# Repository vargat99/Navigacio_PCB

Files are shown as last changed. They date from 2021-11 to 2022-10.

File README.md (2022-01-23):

# KAPCSRAJZON
## Motor control: pipa
## Sensors
	GPS: pipa
	IMU: kéne egy level shifter és egy 1.8V táp
## Power management
	ShengYang datasheet ennyit tudott
## MCU Logic
	GPS, földek be van kötve
	kijövő táp logikai 3.3V, 5V be van kötve
	MCU bemenő táp be van kötve
	
## Kell még
	motor_mode
	motor ki/be kapcsolás
	enkóderek
	pwm vezérlés

	sensorok I2C, SPI ...

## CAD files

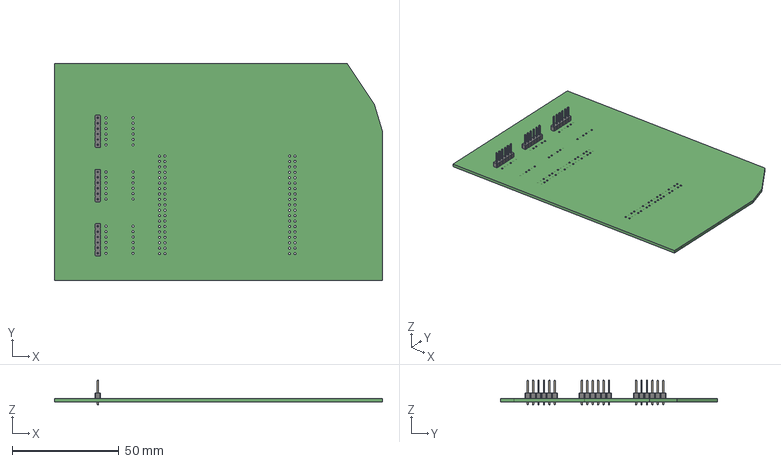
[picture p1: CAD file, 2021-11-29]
lego_robot.step
153.7 x 101.6 x 11.5 mm

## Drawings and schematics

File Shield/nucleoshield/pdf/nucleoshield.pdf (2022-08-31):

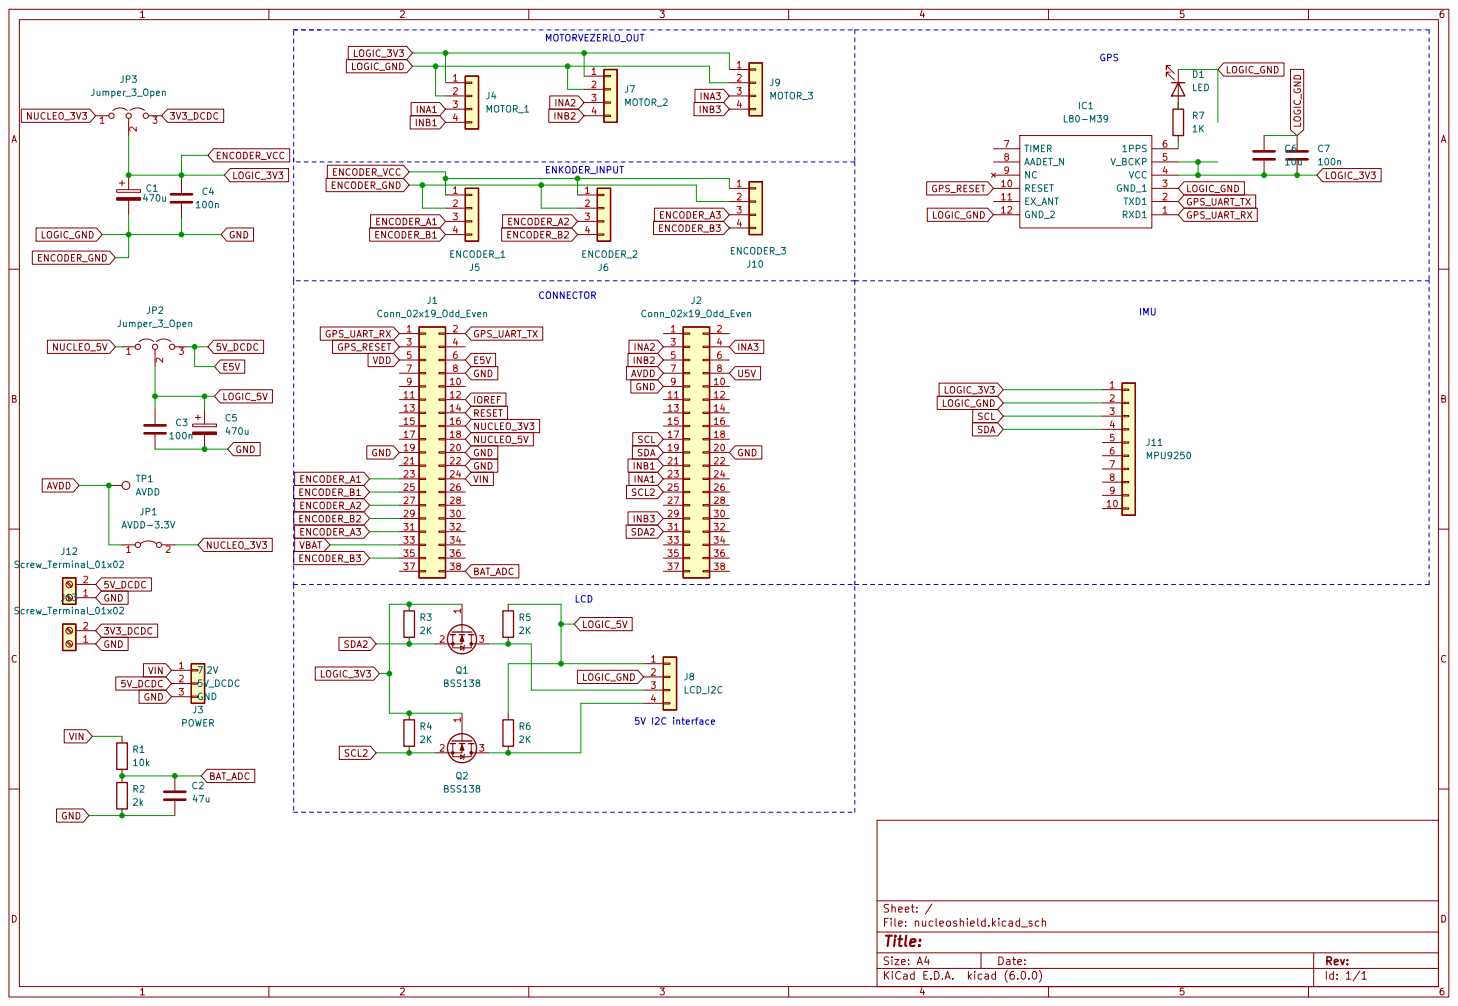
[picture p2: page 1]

ENCODER_VCC | J10 ENCODER_3

J1 Conn_02x19_Odd_Even

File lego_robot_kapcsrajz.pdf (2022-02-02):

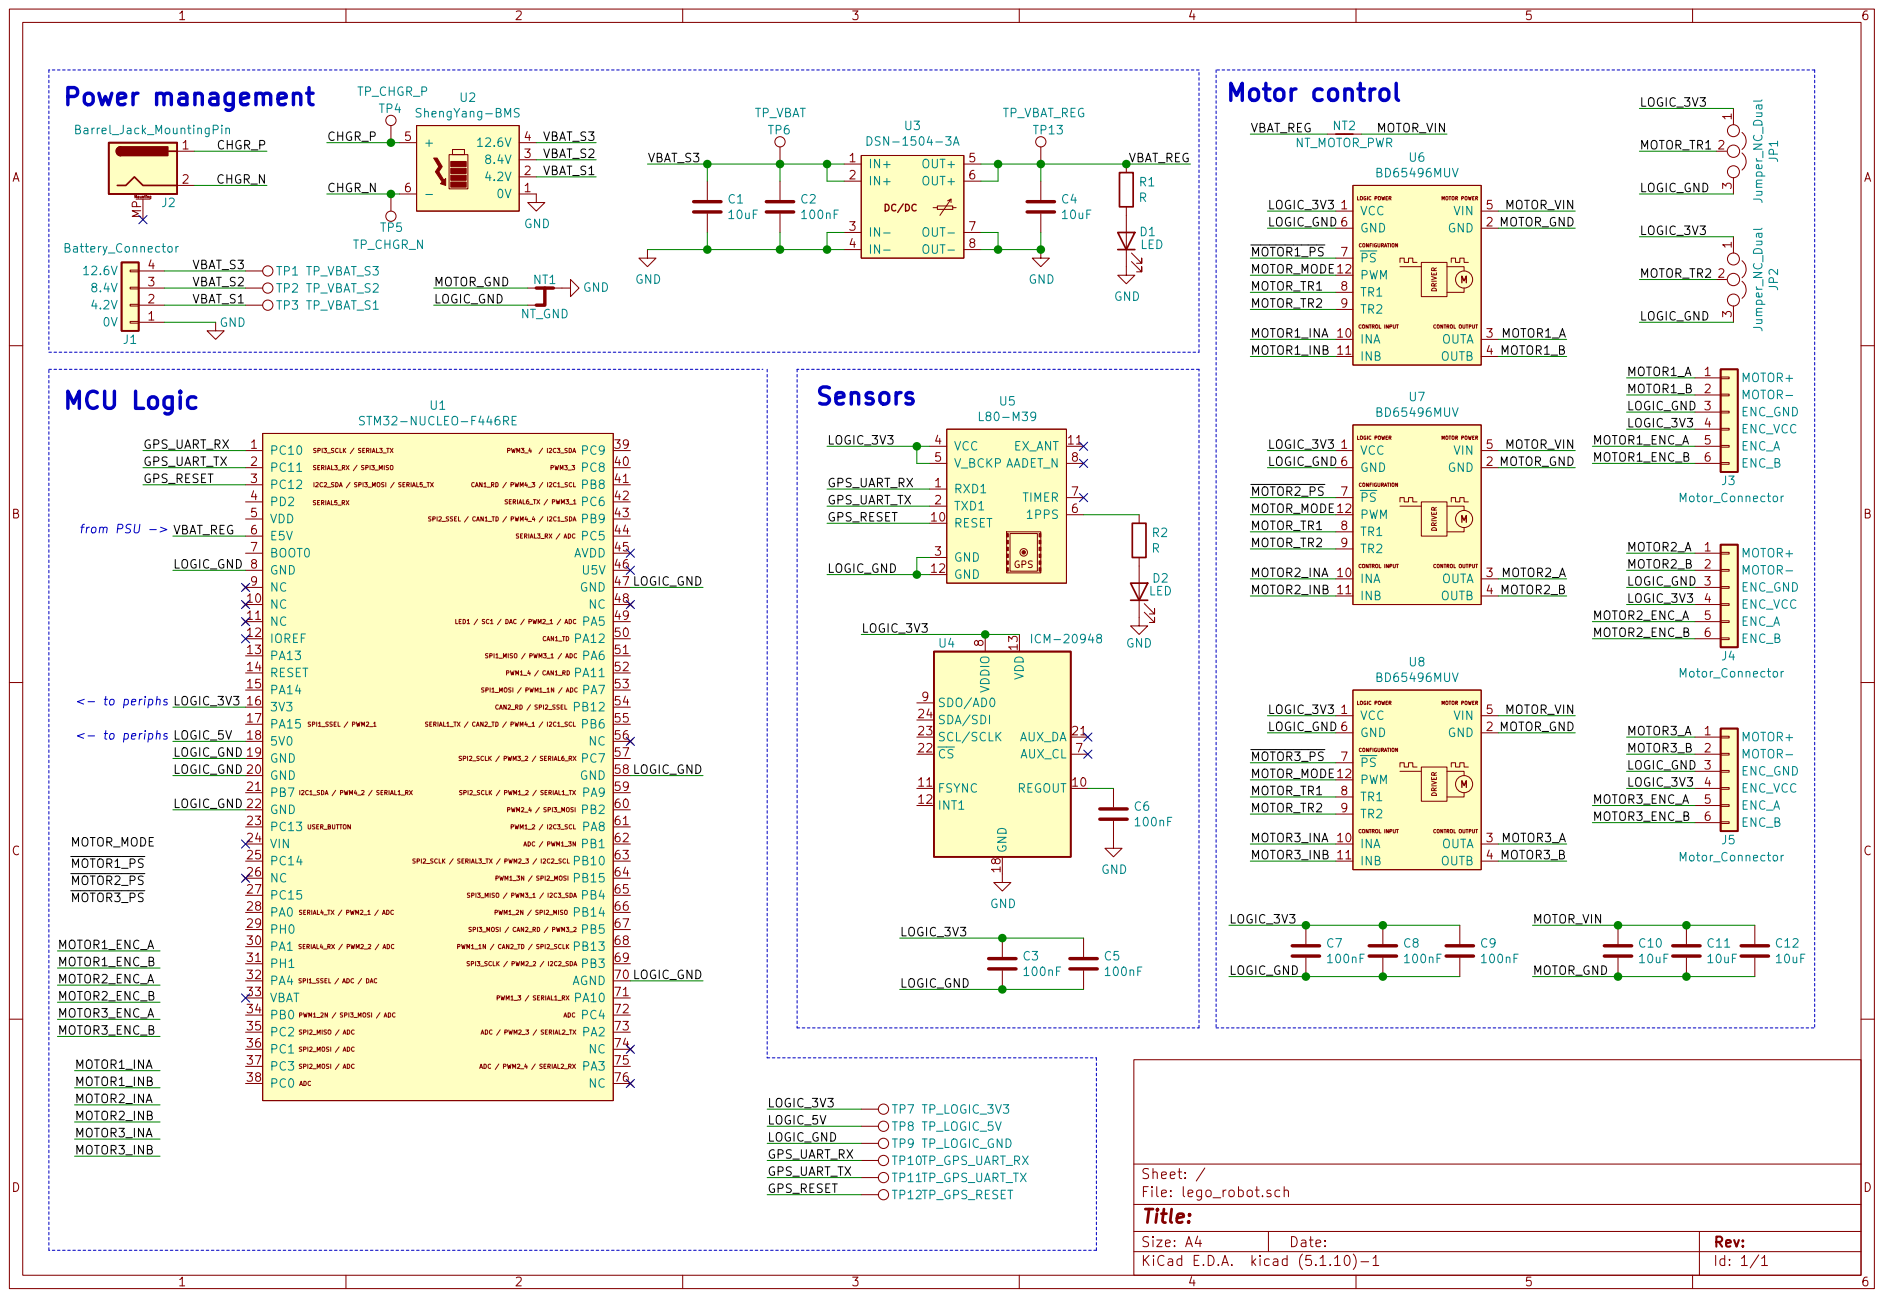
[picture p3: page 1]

from PSU -> MCU Logic

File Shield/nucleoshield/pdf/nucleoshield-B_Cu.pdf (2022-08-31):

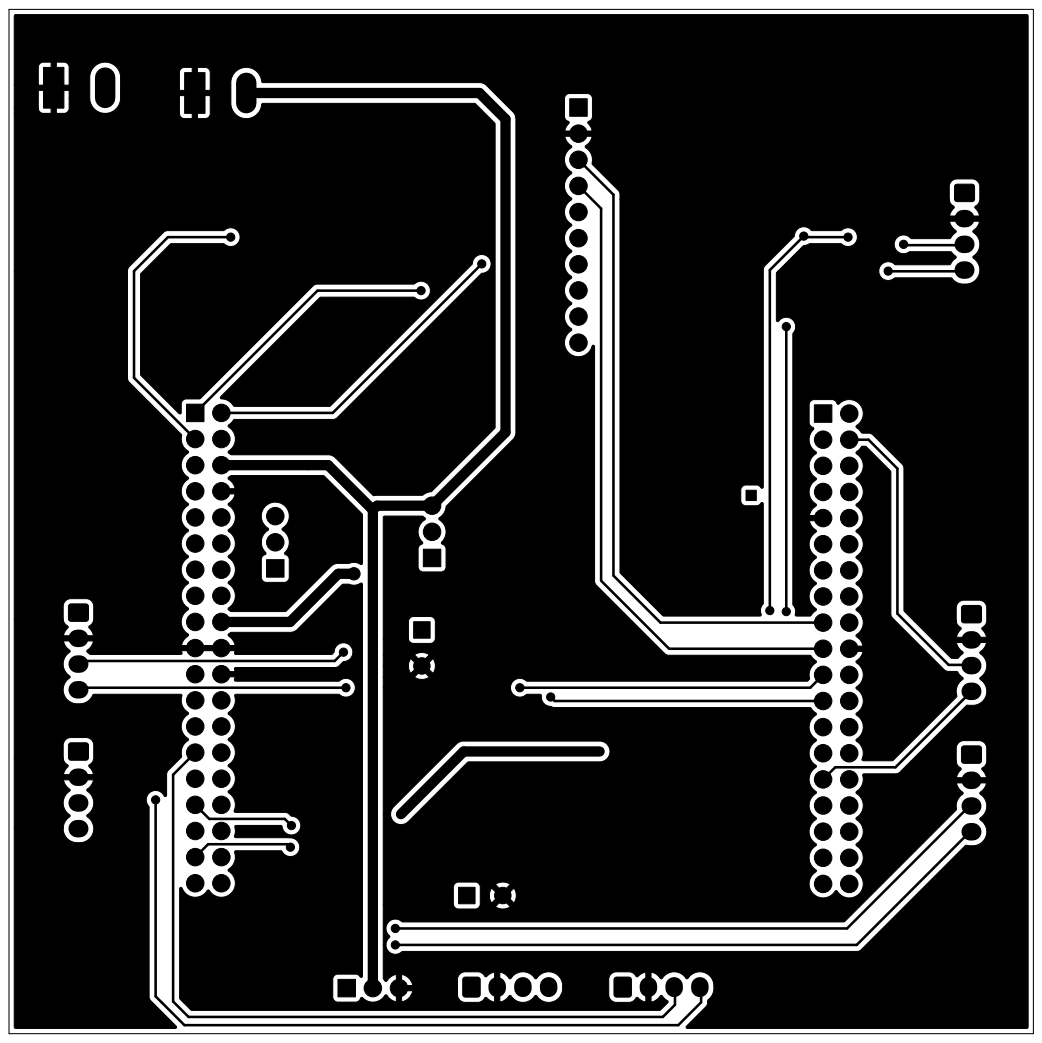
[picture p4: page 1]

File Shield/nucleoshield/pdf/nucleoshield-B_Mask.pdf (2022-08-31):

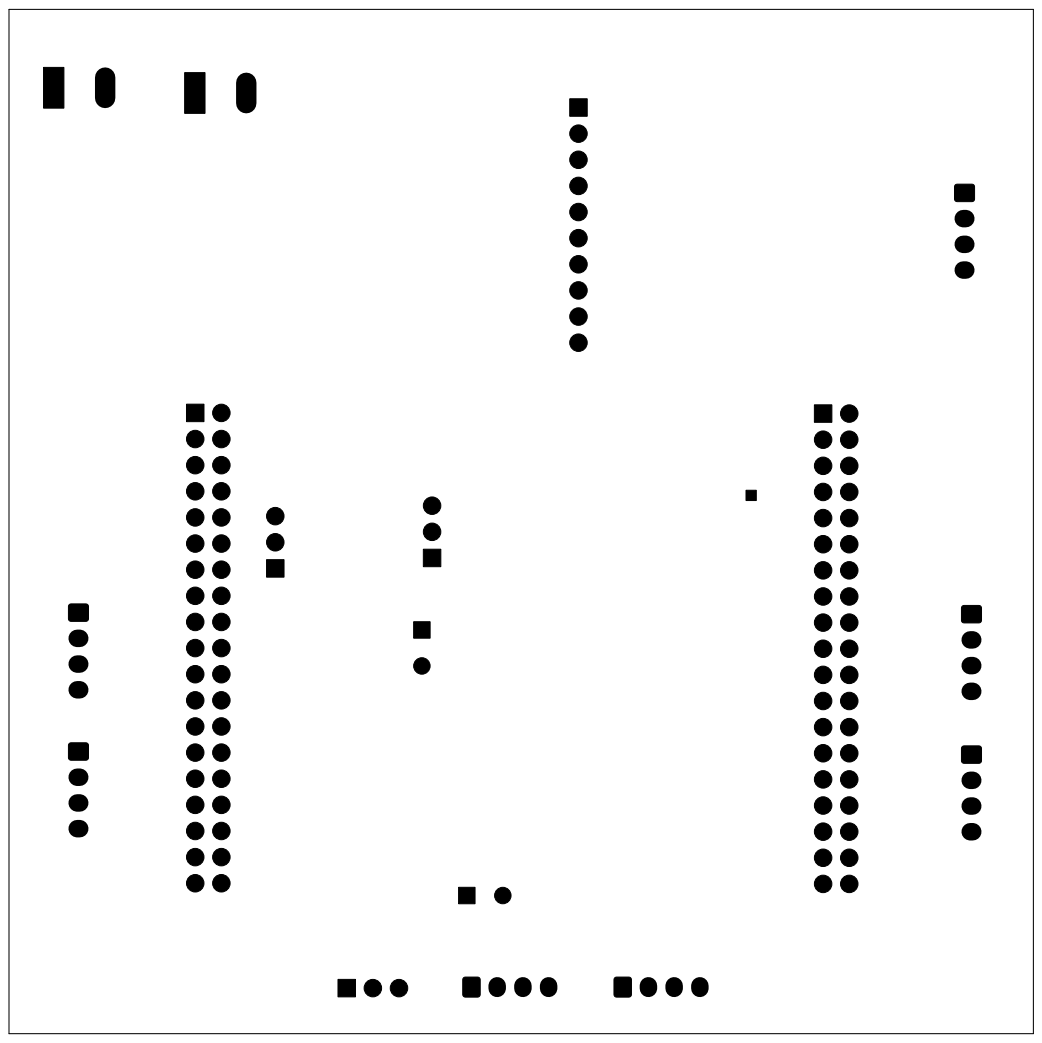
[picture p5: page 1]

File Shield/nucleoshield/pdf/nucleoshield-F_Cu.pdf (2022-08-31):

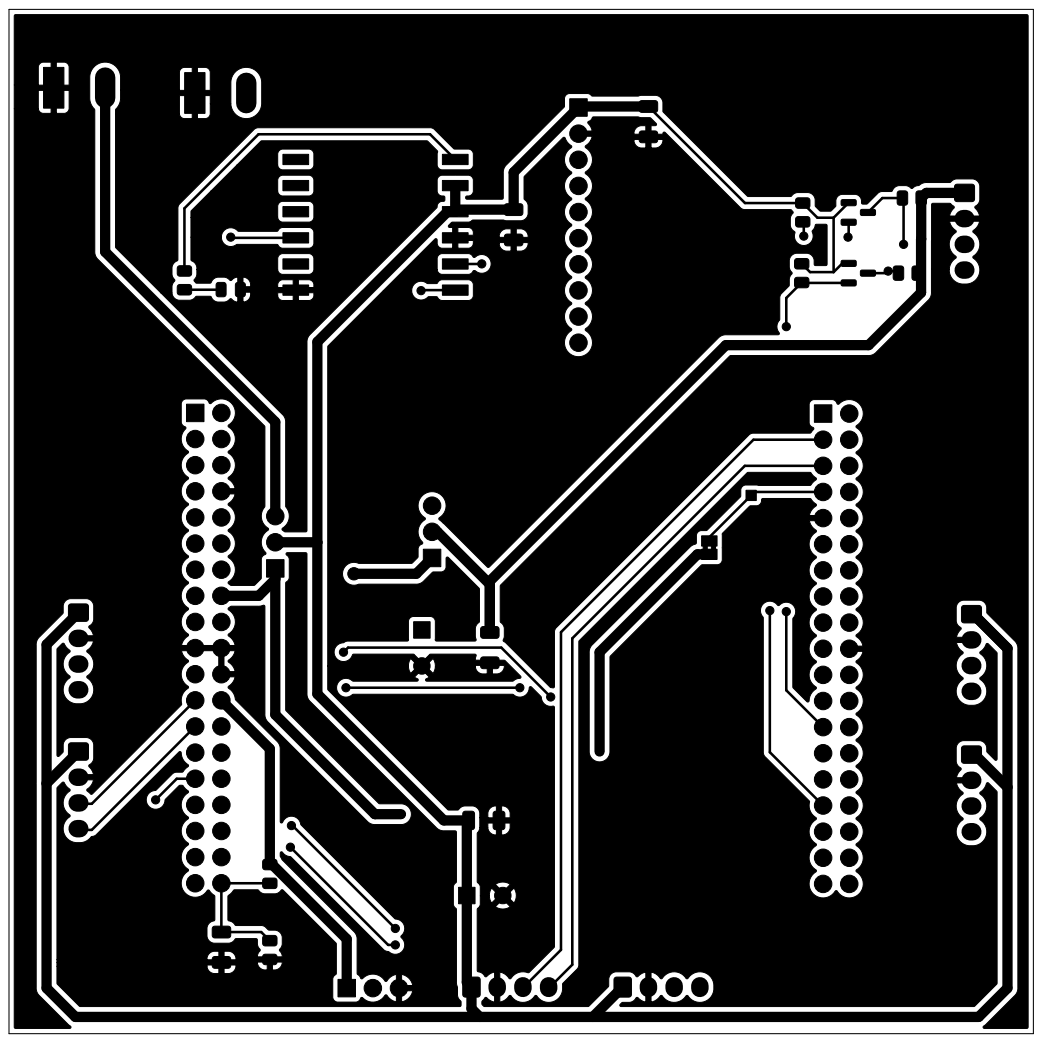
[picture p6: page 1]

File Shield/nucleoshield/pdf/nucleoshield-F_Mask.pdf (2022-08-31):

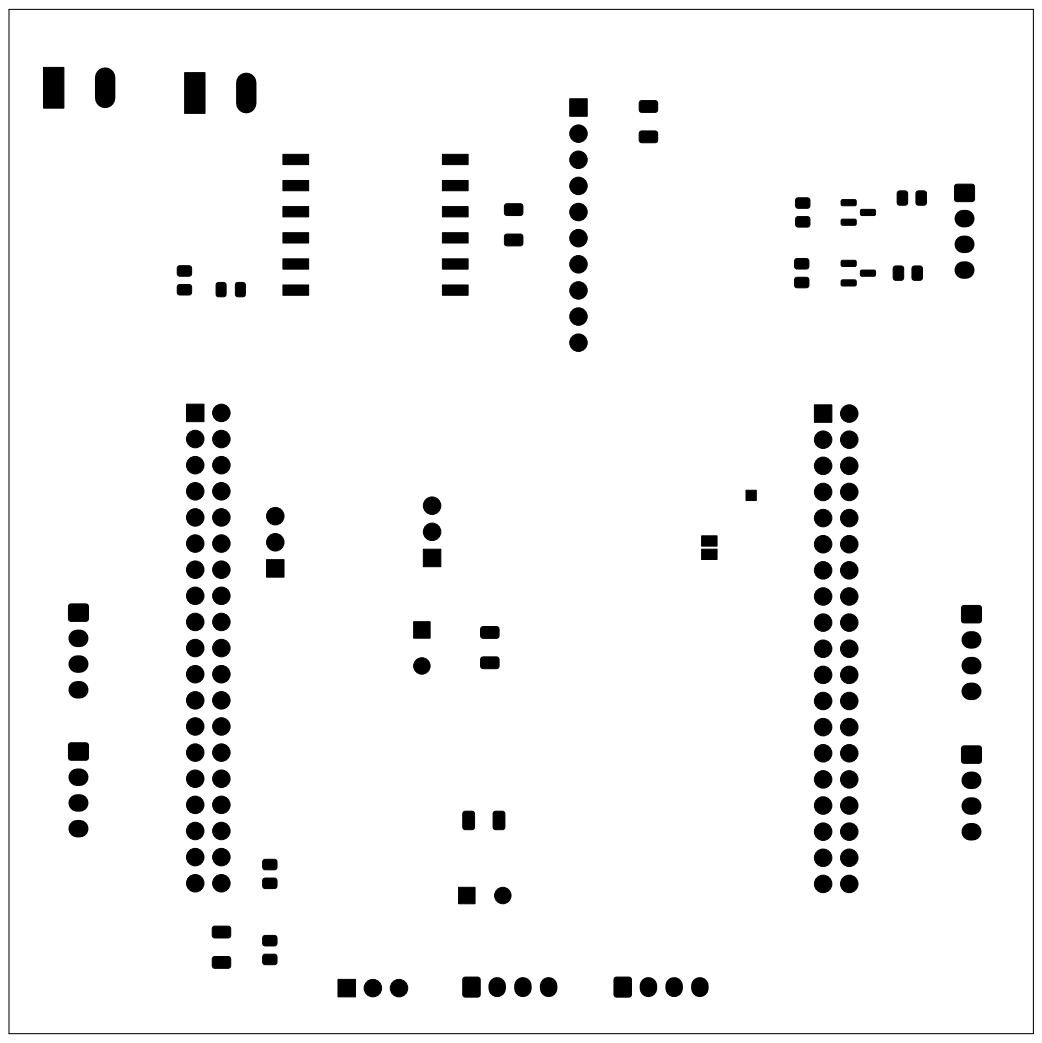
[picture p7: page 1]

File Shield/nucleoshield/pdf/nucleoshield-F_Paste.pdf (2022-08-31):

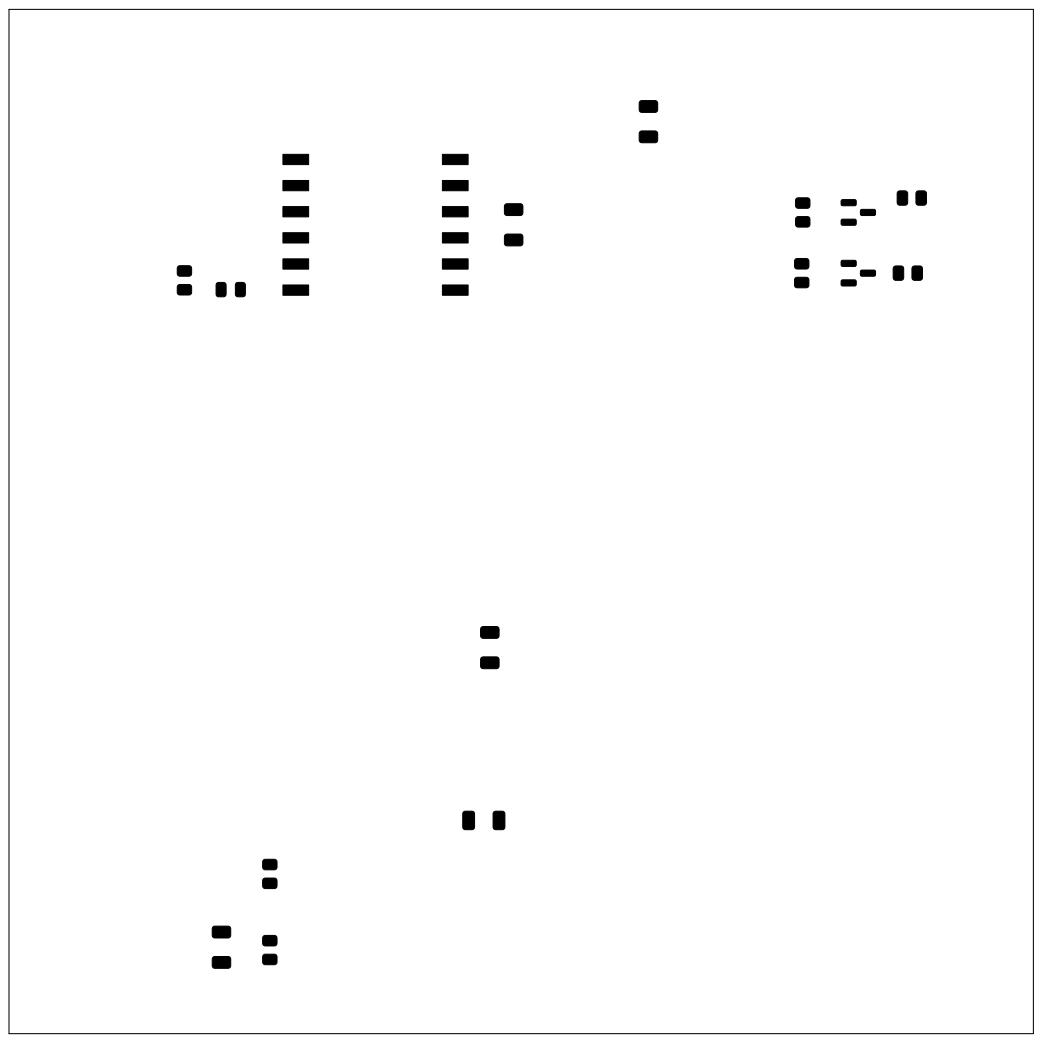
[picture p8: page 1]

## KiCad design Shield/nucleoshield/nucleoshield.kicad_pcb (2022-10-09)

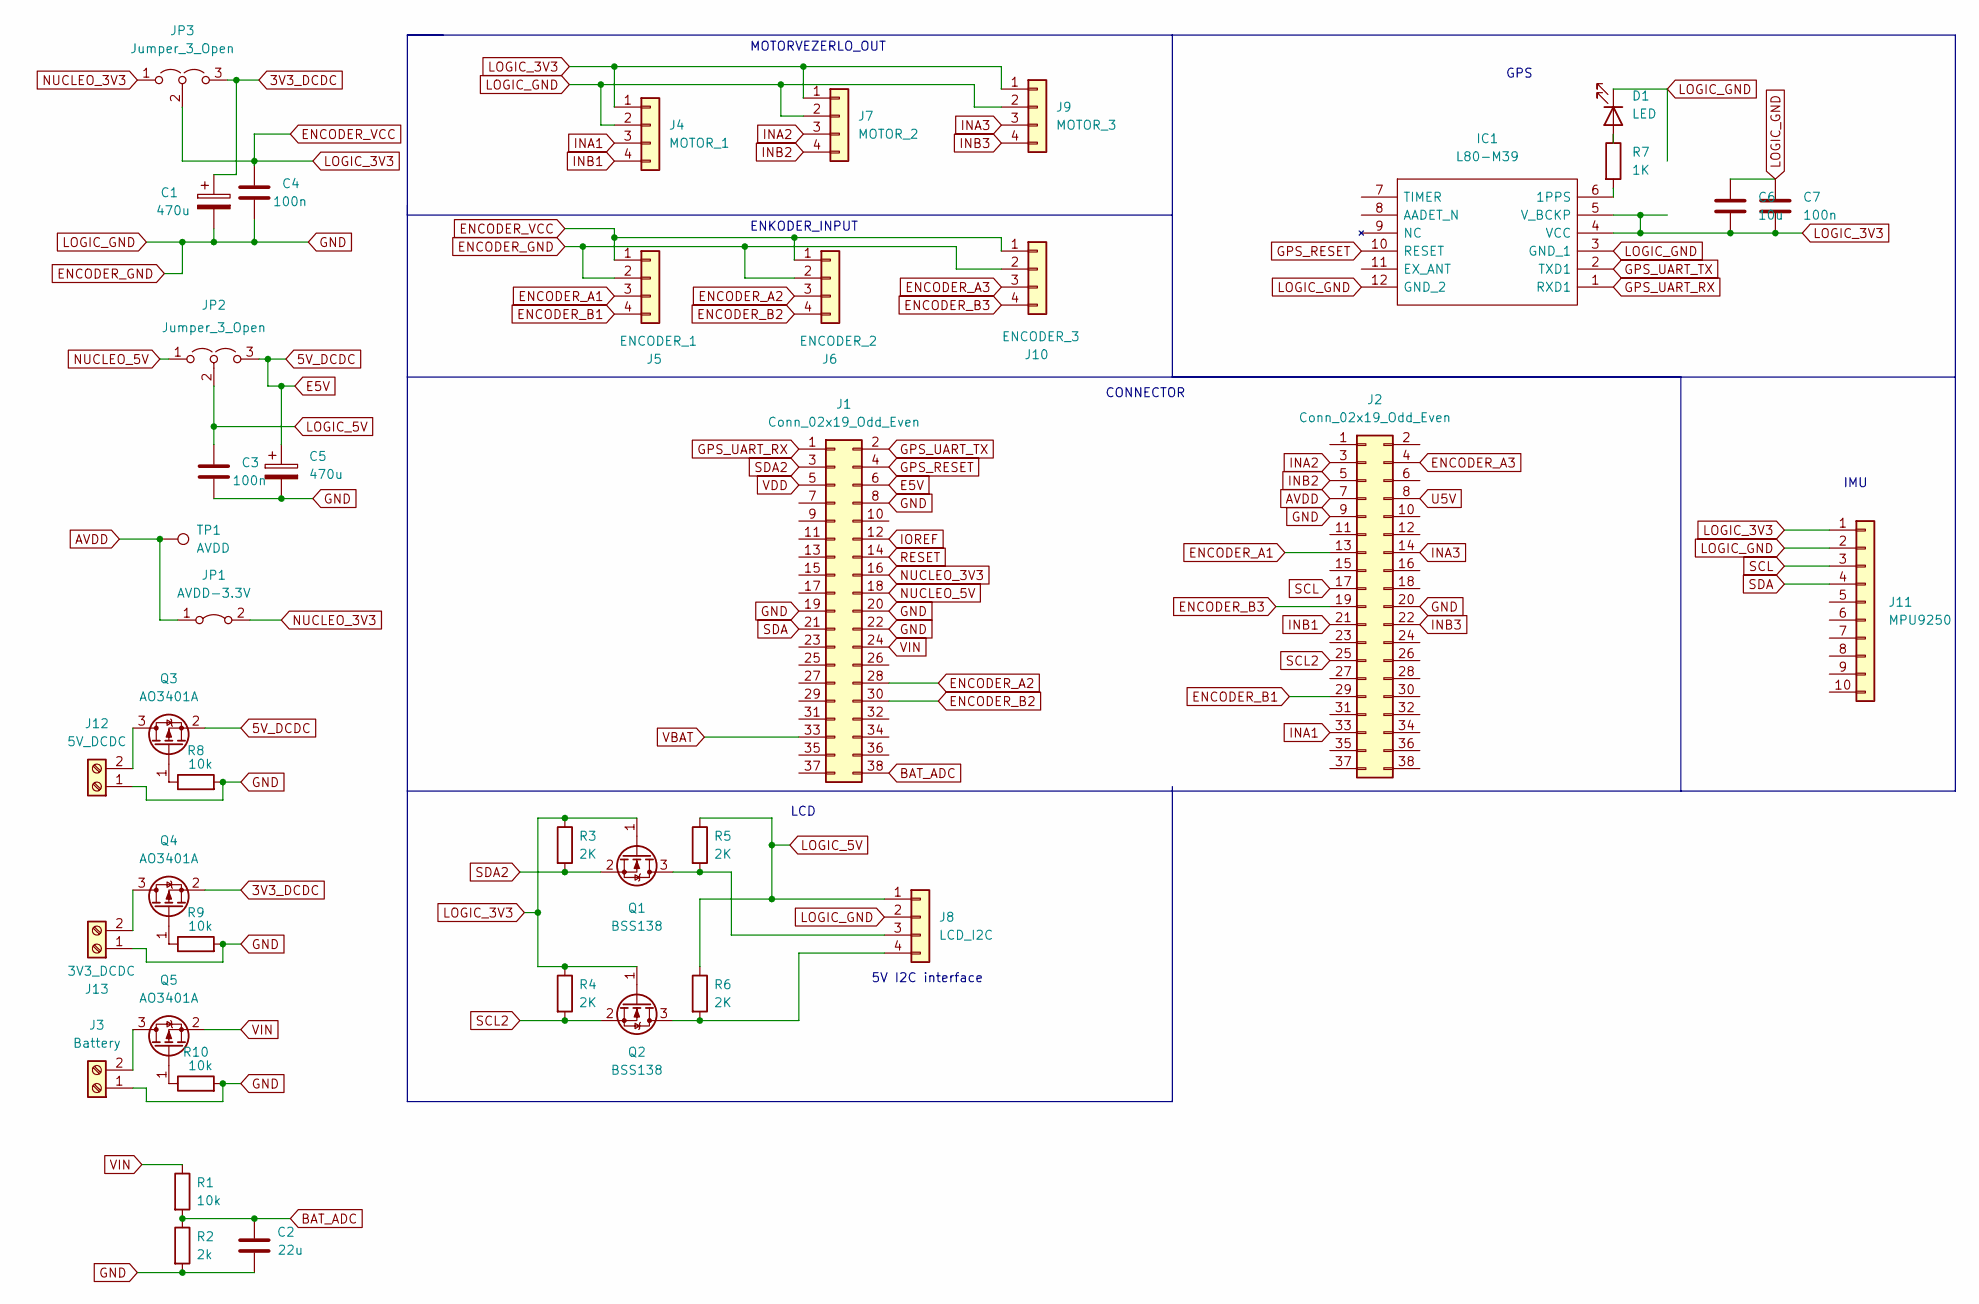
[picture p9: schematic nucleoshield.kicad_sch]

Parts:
C1, C5: 470u; CP_Radial_D8.0mm_P3.50mm
C2: 22u; C_1206_3216Metric
C3, C4, C7: 100n; C_1206_3216Metric
C6: 10u; C_1206_3216Metric
D1: LED; LED_0805_2012Metric
IC1: L80-M39; Manufacturer_Part_Number L80-M39; Mouser Part Number 277-L80-M39
J1, J2: Conn_02x19_Odd_Even; PinSocket_2x19_P2.54mm_Vertical
J3: Battery; TerminalBlock_Altech_AK300-2_P5.00mm
J4: MOTOR_1; JST_EH_B4B-EH-A_1x04_P2.50mm_Vertical
J5: ENCODER_1; JST_EH_B4B-EH-A_1x04_P2.50mm_Vertical
J6: ENCODER_2; JST_EH_B4B-EH-A_1x04_P2.50mm_Vertical
J7: MOTOR_2; JST_EH_B4B-EH-A_1x04_P2.50mm_Vertical
J8: LCD_I2C; JST_EH_B4B-EH-A_1x04_P2.50mm_Vertical
J9: MOTOR_3; JST_EH_B4B-EH-A_1x04_P2.50mm_Vertical
J10: ENCODER_3; JST_EH_B4B-EH-A_1x04_P2.50mm_Vertical
J11: MPU9250; PinHeader_1x10_P2.54mm_Vertical
J12: 5V_DCDC; TerminalBlock_Altech_AK300-2_P5.00mm
J13: 3V3_DCDC; TerminalBlock_Altech_AK300-2_P5.00mm
JP1: AVDD-3.3V; SolderJumper-2_P1.3mm_Bridged2Bar_Pad1.0x1.5mm
JP2, JP3: Jumper_3_Open; PinHeader_1x03_P2.54mm_Vertical
Q1, Q2: BSS138; SOT-23
Q3, Q4, Q5: AO3401A; SOT-23
R1, R8, R9, R10: 10k; R_0805_2012Metric
R2: 2k; R_0805_2012Metric
R3, R4, R5, R6: 2K; R_0805_2012Metric
R7: 1K; R_0805_2012Metric
TP1: AVDD; TestPoint_THTPad_1.0x1.0mm_Drill0.5mm

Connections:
3V3_DCDC: C1.1, JP3.3 (B), Q4.2 (S)
5V_DCDC: C5.1, J1.6, JP2.3 (B), Q3.2 (S)
AVDD: J2.7, JP1.1 (A), TP1.1
BAT_ADC: C2.2, J1.38, R1.2, R2.1
ENCODER_A1: J2.13, J5.3
ENCODER_A2: J1.28, J6.3
ENCODER_A3: J2.4, J10.3
ENCODER_B1: J2.29, J5.4
ENCODER_B2: J1.30, J6.4
ENCODER_B3: J2.19, J10.4
ENCODER_GND: C1.2, C2.1, C3.2, C4.2, C5.2, C6.1, C7.1, D1.1 (K), IC1.3 (GND_1), IC1.12 (GND_2), J1.8, J1.19, J1.20, J1.22, J2.9, J2.20, J3.1, J4.2, J5.2, J6.2, J7.2, J8.2, J9.2, J10.2, J11.2, J12.1, J13.1, R2.2, R8.2, R9.2, R10.2
ENCODER_VCC: C4.1, C6.2, C7.2, IC1.4 (VCC), IC1.5 (V_BCKP), J4.1, J5.1, J6.1, J7.1, J9.1, J10.1, J11.1, JP3.2 (C), Q1.1 (G), Q2.1 (G), R3.1, R4.1
GPS_RESET: IC1.10 (RESET), J1.4
GPS_UART_RX: IC1.1 (RXD1), J1.1
GPS_UART_TX: IC1.2 (TXD1), J1.2
INA1: J2.33, J4.3
INA2: J2.3, J7.3
INA3: J2.14, J9.3
INB1: J2.21, J4.4
INB2: J2.5, J7.4
INB3: J2.22, J9.4
IOREF: J1.12
LOGIC_5V: C3.1, J8.1, JP2.2 (C), R5.1, R6.1
NUCLEO_3V3: J1.16, JP1.2 (B), JP3.1 (A)
NUCLEO_5V: J1.18, JP2.1 (A)
unnamed: D1.2 (A), R7.1
unnamed: IC1.6 (1PPS), R7.2
unnamed: J3.2, Q5.3 (D)
unnamed: J8.3, Q1.3 (D), R5.2
unnamed: J8.4, Q2.3 (D), R6.2
unnamed: J12.2, Q3.3 (D)
unnamed: J13.2, Q4.3 (D)
unnamed: Q3.1 (G), R8.1
unnamed: Q4.1 (G), R9.1
unnamed: Q5.1 (G), R10.1
RESET: J1.14
SCL: J2.17, J11.3
SCL2: J2.25, Q2.2 (S), R4.2
SDA: J1.21, J11.4
SDA2: J1.3, Q1.2 (S), R3.2
U5V: J2.8
VBAT: J1.33
VDD: J1.5
VIN: J1.24, Q5.2 (S), R1.1

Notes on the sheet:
IMU
CONNECTOR
ENKODER_INPUT
5V I2C interface
LCD
GPS
MOTORVEZERLO_OUT

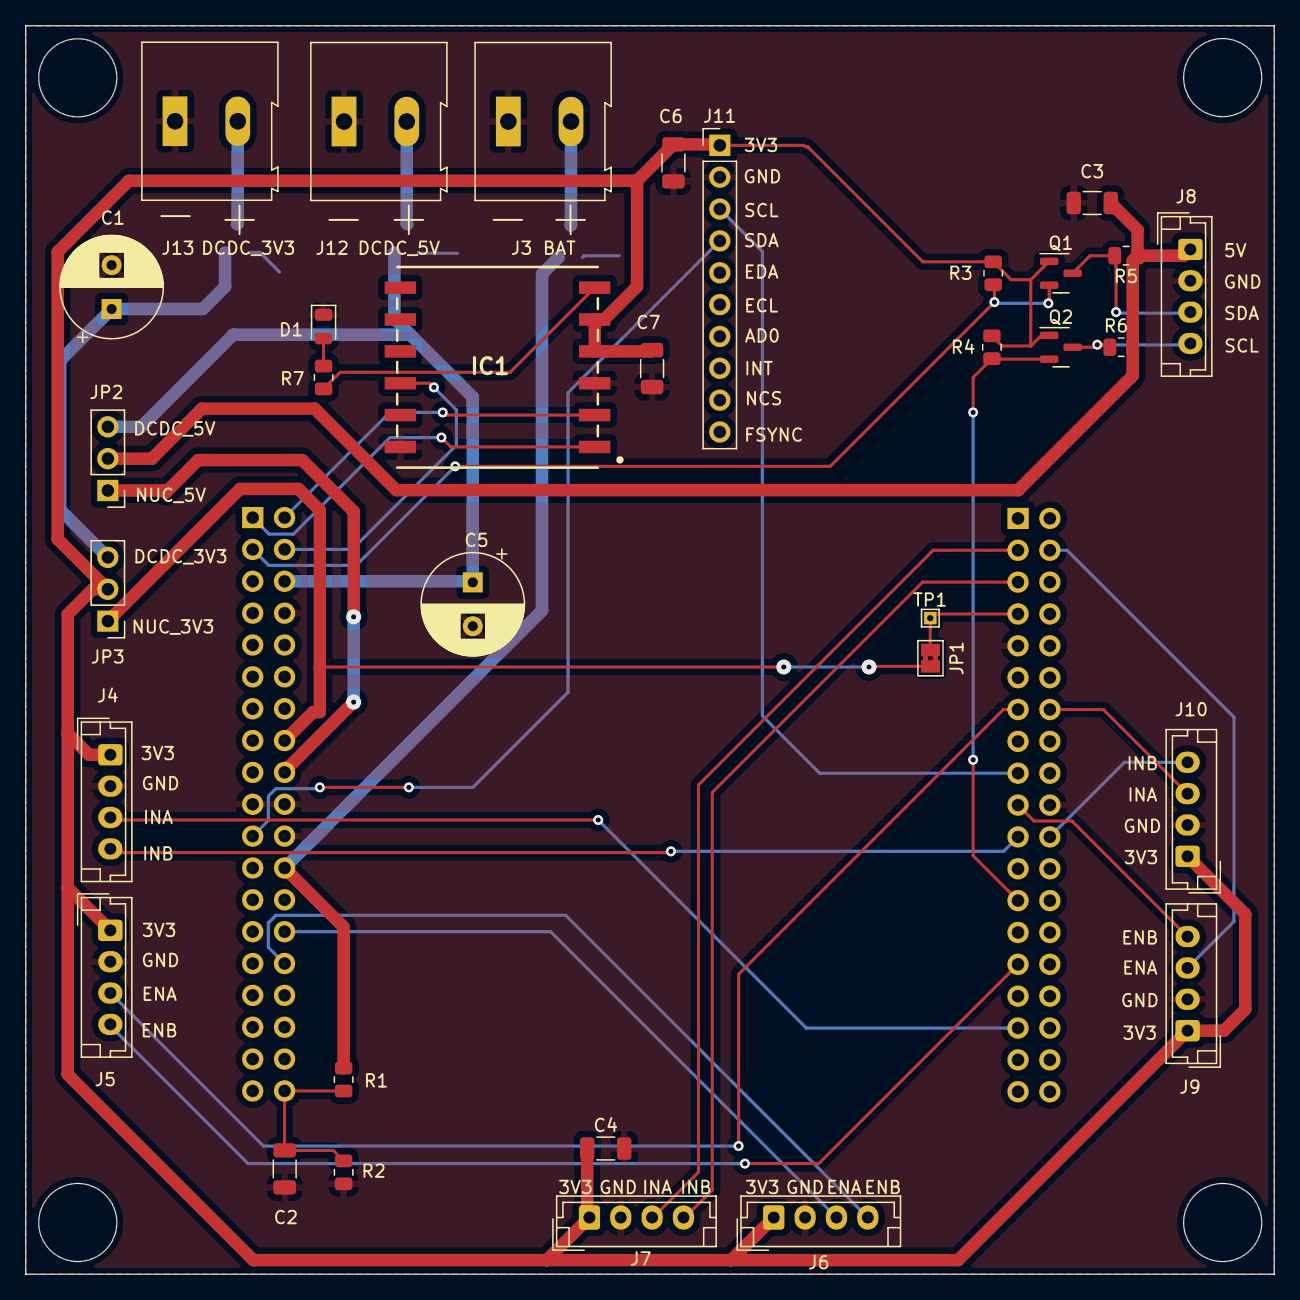
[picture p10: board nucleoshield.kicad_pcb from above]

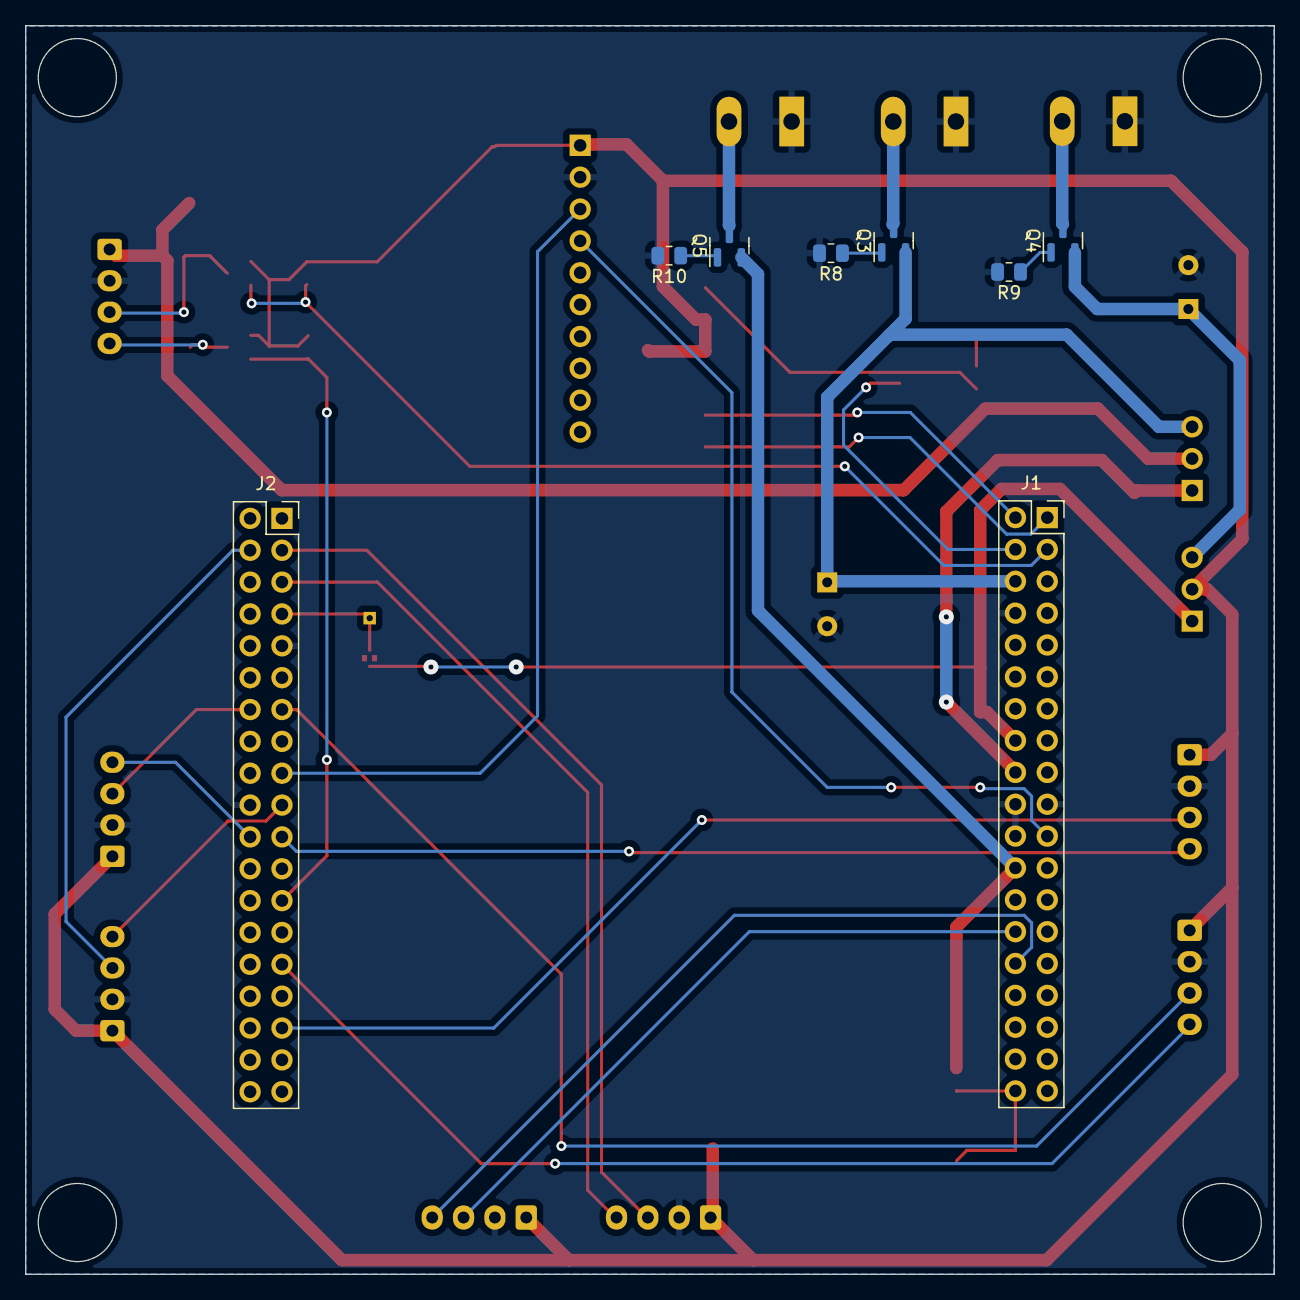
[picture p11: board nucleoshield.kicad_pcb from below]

Board: 2 copper layers, 99.6 x 99.6 mm, 41 parts (8 on the bottom side), 39 nets.

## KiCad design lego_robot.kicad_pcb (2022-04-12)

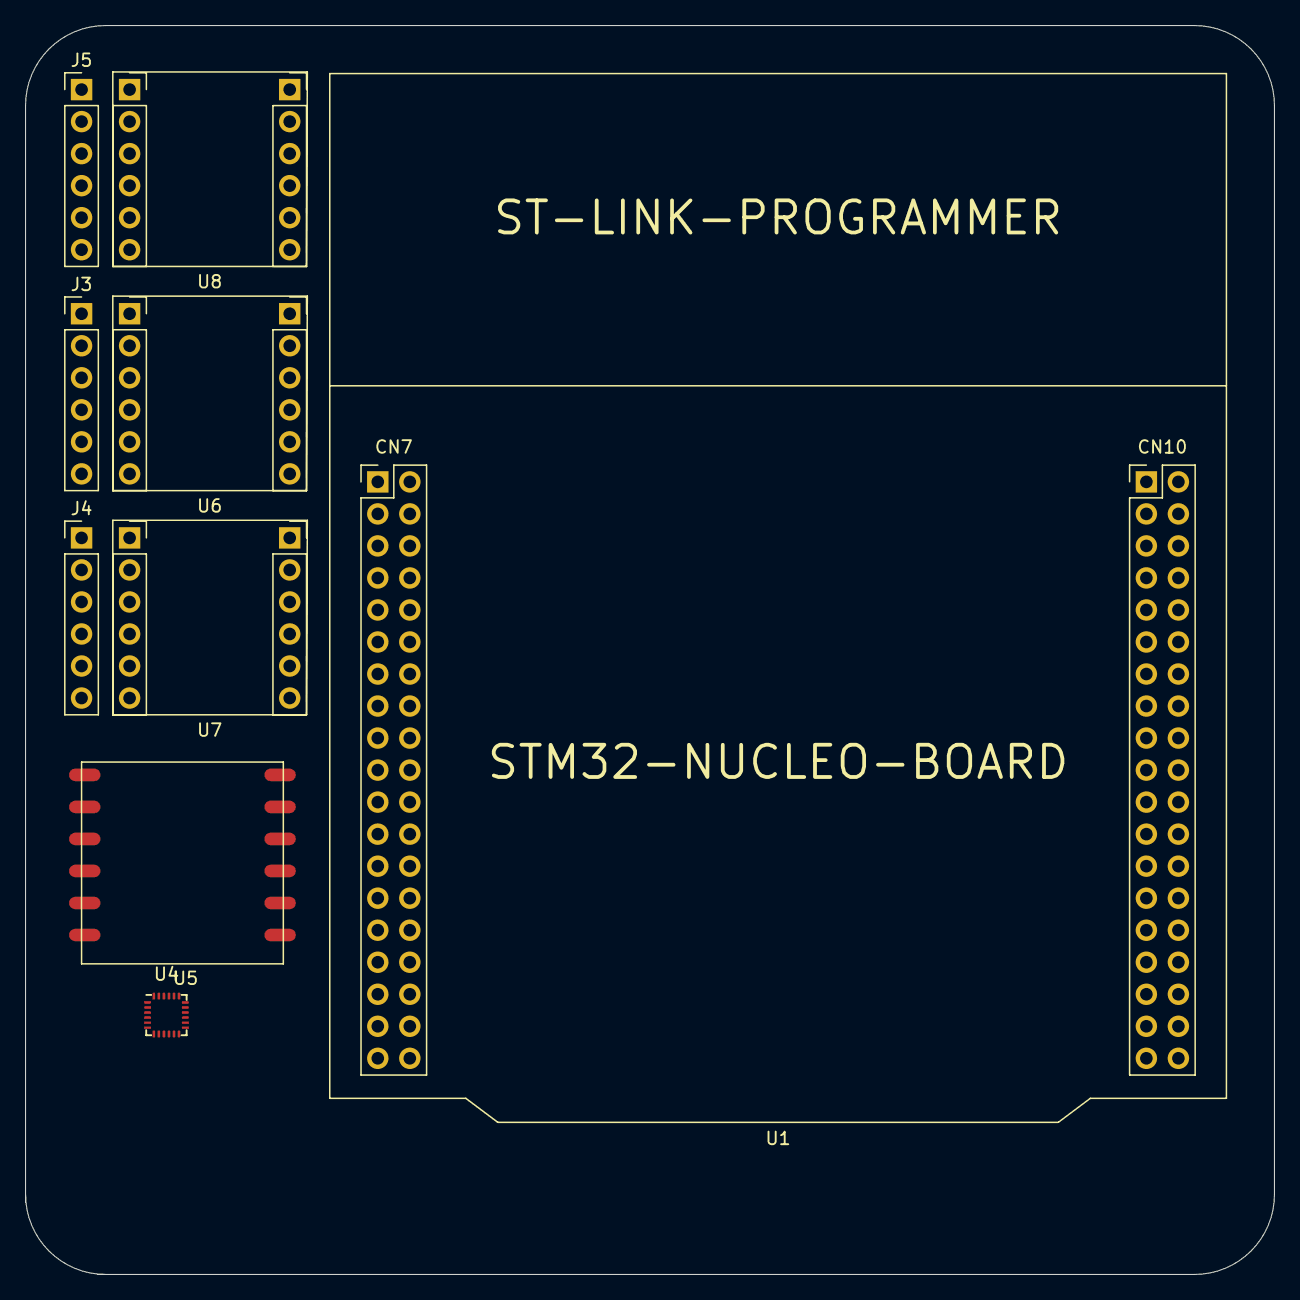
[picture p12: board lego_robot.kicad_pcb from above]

Board: 2 copper layers, 99.1 x 99.1 mm, 9 parts (0 on the bottom side), 17 nets, no tracks yet.

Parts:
J3, J4, J5: Motor_Connector; PinHeader_1x06_P2.54mm_Vertical
U1: STM32-NUCLEO-F446RE; ST_NUCLEO64
U4: ICM-20948; InvenSense_QFN-24_3x3mm_P0.4mm
U5: L80-M39
U6, U7, U8: BD65496MUV

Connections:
/GPS_RESET: U1.3, U5.10
/GPS_UART_RX: U1.1, U5.1
/GPS_UART_TX: U1.2, U5.2
/LOGIC_3V3: J3.4, J4.4, J5.4, U1.16, U4.8, U4.13, U5.4, U5.5, U6.1, U7.1, U8.1
/LOGIC_GND: J3.3, J4.3, J5.3, U1.8, U1.19, U1.20, U1.22, U1.47, U1.58, U1.70, U5.3, U5.12, U6.6, U7.6, U8.6
/MOTOR1_A: J3.1, U6.3
/MOTOR1_B: J3.2, U6.4
/MOTOR2_A: J4.1, U7.3
/MOTOR2_B: J4.2, U7.4
/MOTOR3_A: J5.1, U8.3
/MOTOR3_B: J5.2, U8.4
/MOTOR_GND: U6.2, U7.2, U8.2
/MOTOR_MODE: U6.12, U7.12, U8.12
/MOTOR_TR1: U6.8, U7.8, U8.8
/MOTOR_TR2: U6.9, U7.9, U8.9
/MOTOR_VIN: U6.5, U7.5, U8.5
GND: U4.18, U4.20

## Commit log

2021-11-29 init commit
    [lego_robot.kicad_pcb, lego_robot.sch, lego_robot.step]
2022-01-23 More work on schematic
    [lego_robot.sch]
2022-01-23 Preliminary PCB edge cuts and placements
    [lego_robot.kicad_pcb]
2022-04-12 mostly done
    [lego_robot.kicad_pcb, lego_robot.kicad_sch, nucleoshield.kicad_pcb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]
2022-08-15 Nucleo shield
    [nucleoshield.kicad_sch]
2022-08-25 Schematic and pcb ready
    [nucleoshield.kicad_pcb, nucleoshield.kicad_sch]
2022-08-27 power modifications
    [nucleoshield.kicad_pcb, nucleoshield.kicad_sch]
2022-08-30 Power connector
    [nucleoshield.kicad_pcb, nucleoshield.kicad_sch]
2022-08-31 small changes
    [nucleoshield.kicad_pcb, nucleoshield.kicad_sch]
2022-09-06 Csatlakozók megváltoztatva, polaritásvédelem, apróbb javítások
    [nucleoshield.kicad_pcb, nucleoshield.kicad_sch]
2022-09-16 Fetek kicserélve
    [nucleoshield.kicad_pcb, nucleoshield.kicad_sch]
2022-09-25 Enkóderek timer bemenetekhez rendelve
    [nucleoshield.kicad_pcb, nucleoshield.kicad_sch]
2022-10-09 DRC update
    [nucleoshield.kicad_pcb]
2023-12-13 Schematic update
    [nucleoshield.kicad_sch]
